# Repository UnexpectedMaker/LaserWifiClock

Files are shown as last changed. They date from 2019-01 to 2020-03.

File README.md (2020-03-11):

# Mod-able Laser Wifi Clock
Design files and code for my open source Mod-able RGB Laser Wifi Clock that I sell on tindie:
https://www.tindie.com/products/15501/

Laser Wifi Clock

It's custom hardware and custom code but all open source so if you want the challenge of making one yourself or you want to hack the code, go for it!

I have a live stream build of the board here if you want to see what's involved:
https://www.youtube.com/watch?v=2W7_SHC2Mis

# Design Files
Inlcluded in this reposity:
- EagleCAD schematics and Board layout files (Eagle 9.2) 
- Exported Gerber files (Gerber 274X)
- STL & DXF files for the 3D printed case and laser cut pieces
- Adrduino code

# Assembling the case
Here is a video guide to assembling the case

https://youtu.be/fARj-D6XGP0

# Hacking the code
You will need to have the ESP8266 board for Arduino IDE installed. If you don't, you can follow the instructions here:
https://arduino-esp8266.readthedocs.io/en/2.5.0-beta2/installing.html

Laser Wifi Clock

Once installed you'll need to select the *LOLIN(WEMOS) D1 R2 & Mini* as the board type.

Plus the following libraries from Library Manager
- One Button
- TimeLib
- WifiManager (tzapu)
- ArduinoJson

Enjoy!

# Support Unexpected Maker

I love designing, making and releasing our projects as open source. I do it because I believe it’s important to share knowledge and give back to the community, like many have done before me. It helps us all learn and grow.

That said, a lot of time, effort and finances have gone into designing and releasing these files, so please consider supporting me by buy some of my TiinyPICO products:

https://tinypico.com/shop

Or by buying one of our products on tindie:

https://www.tindie.com/stores/seonr/

Or by becoming a Patron:

https://www.patreon.com/unexpectedmaker

# Unexpected Maker
http://youtube.com/c/unexpectedmaker

http://twitter.com/unexpectedmaker

https://www.facebook.com/unexpectedmaker/

https://www.instagram.com/unexpectedmaker/

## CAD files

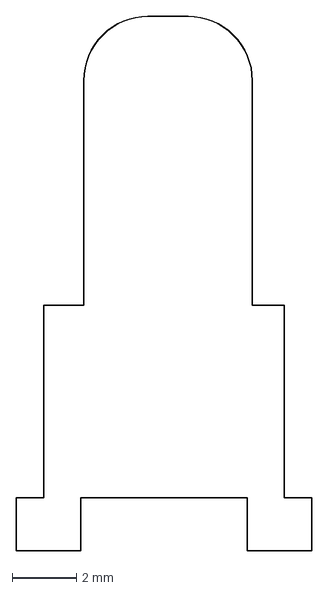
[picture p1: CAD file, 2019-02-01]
DXF/Clock_Segments_Short.dxf
9.20 x 16.7 mm

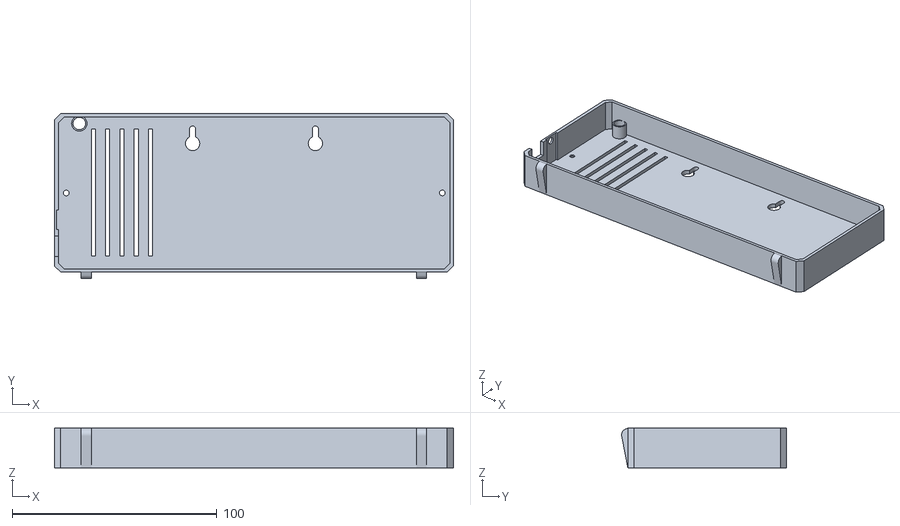
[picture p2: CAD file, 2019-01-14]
STL/WifiClock_Back.stl
195.0 x 80.6 x 19.5

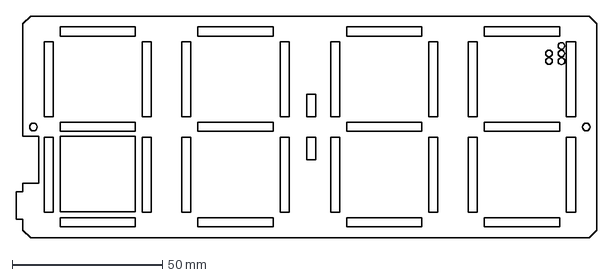
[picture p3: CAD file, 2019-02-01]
DXF/WifiClock_Acrylic_Middle.dxf
193.0 x 73.7 mm

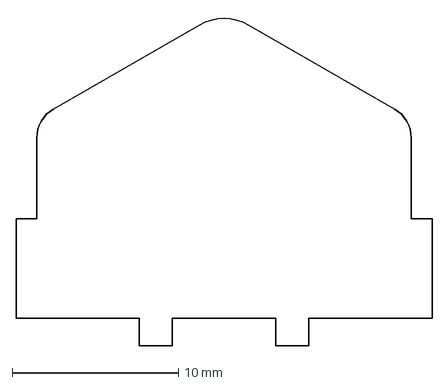
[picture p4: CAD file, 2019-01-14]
DXF/Clock_Segments_Long.dxf
25.0 x 19.8 mm

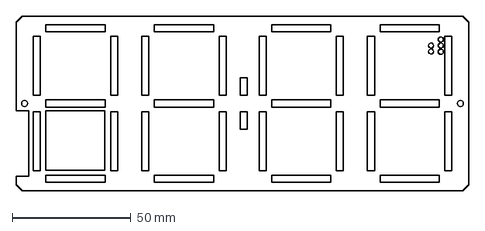
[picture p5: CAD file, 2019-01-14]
DXF/WifiClock_Acrylic_Back.dxf
190.8 x 73.7 mm

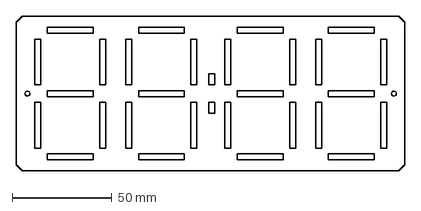
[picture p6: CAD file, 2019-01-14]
DXF/WifiClock_Acrylic_Front.dxf
195.0 x 77.6 mm

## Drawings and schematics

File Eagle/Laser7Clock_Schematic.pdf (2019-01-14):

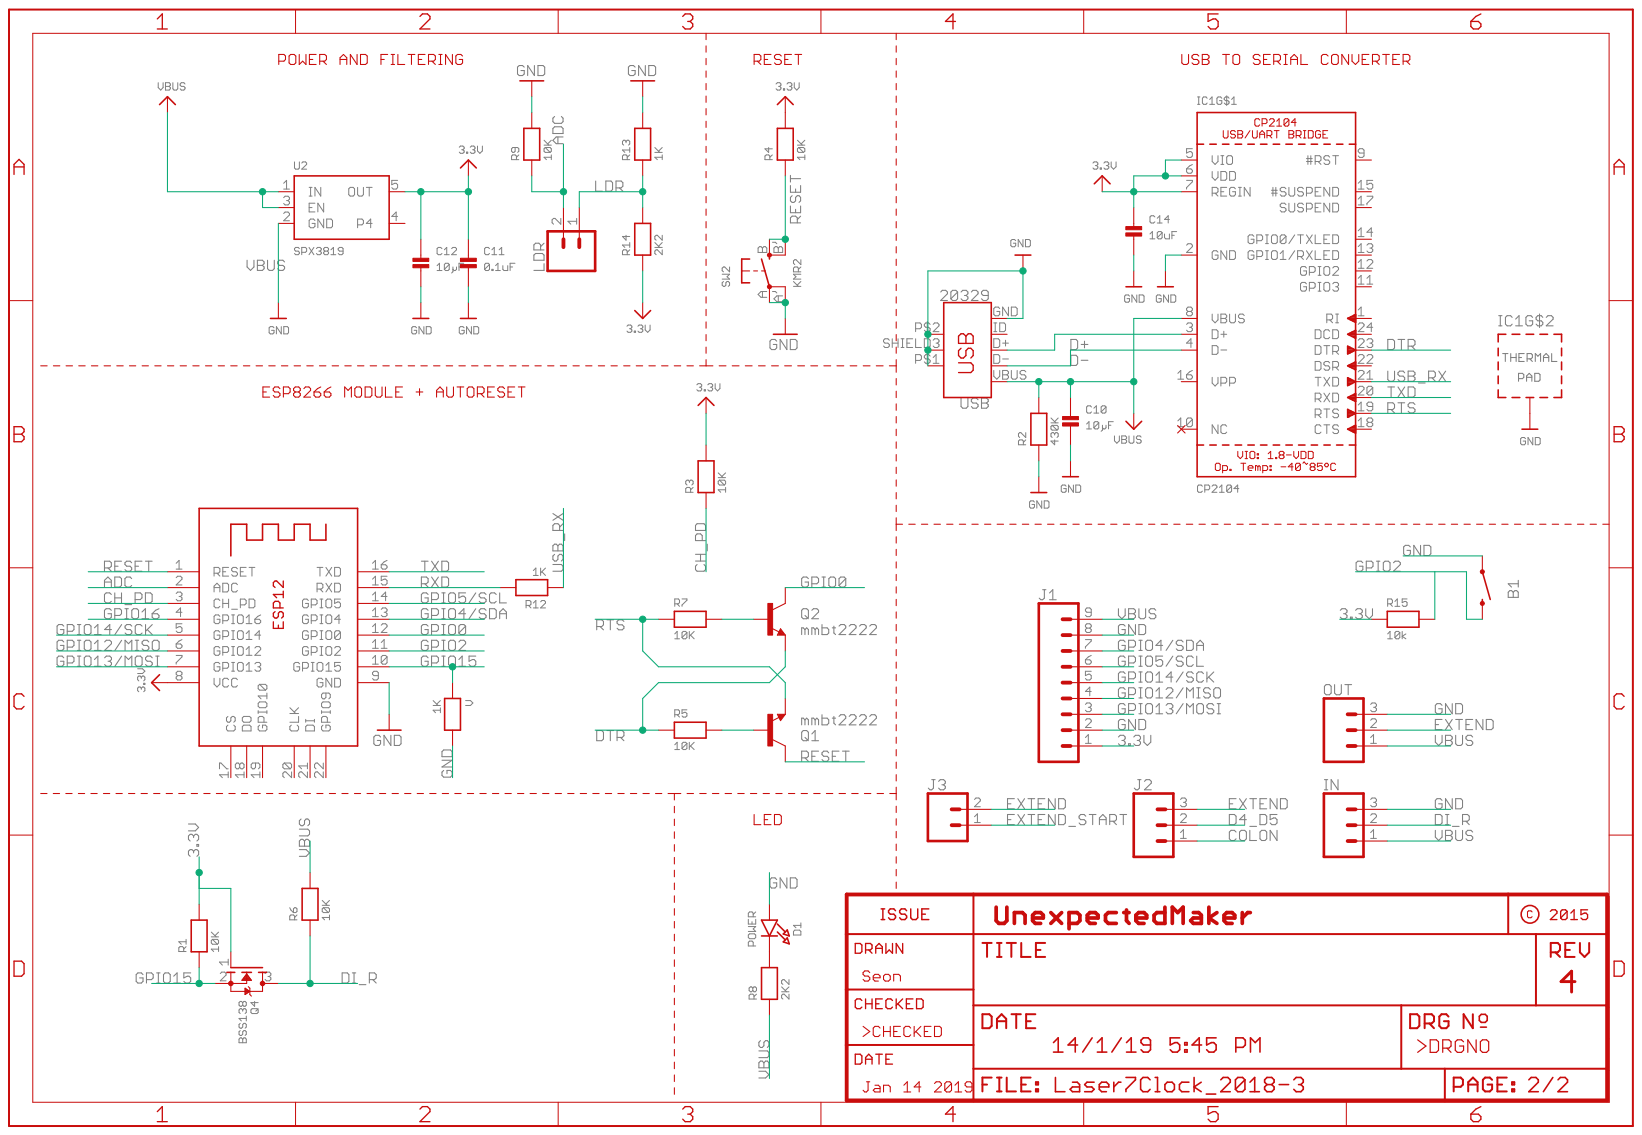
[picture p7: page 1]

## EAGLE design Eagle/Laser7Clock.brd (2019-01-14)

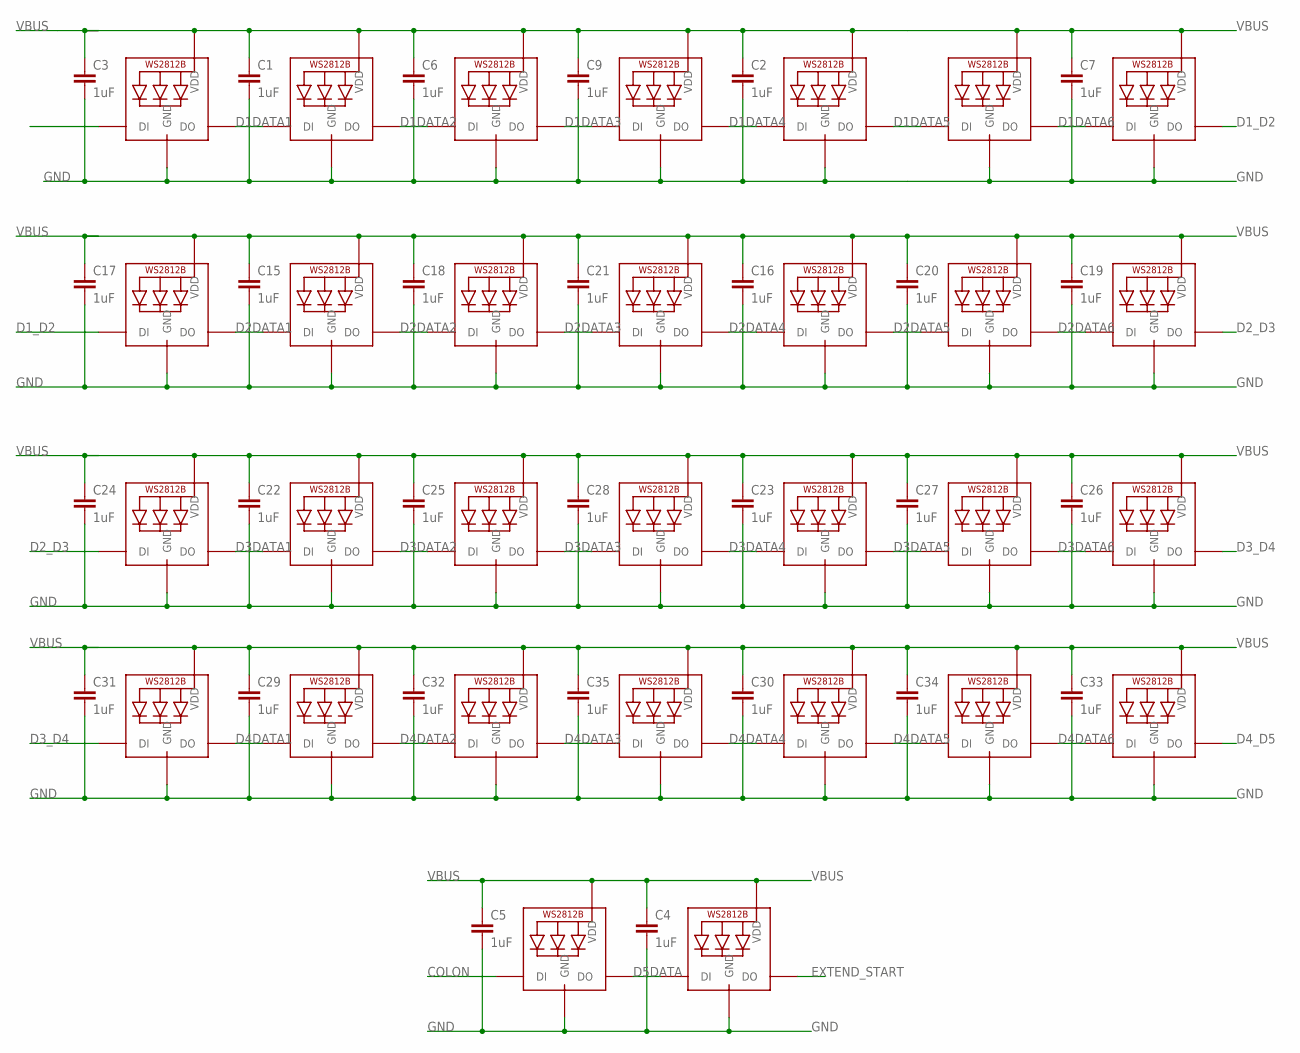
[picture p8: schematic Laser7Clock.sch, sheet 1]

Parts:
C1, C2, C3, C4, C5, C6, C7, C9, C15, C16, C17, C18, C19, C20, C21, C22, C23, C24, C25, C26, C27, C28, C29, C30, C31, C32, C33, C34, C35: 1uF; C0805K
D1L1, D1L2, D1L3, D1L4, D1L5, D1L6, D1L7, D2L1, D2L2, D2L3, D2L4, D2L5, D2L6, D2L7, D3L1, D3L2, D3L3, D3L4, D3L5, D3L6, D3L7, D4L1, D4L2, D4L3, D4L4, D4L5, D4L6, D4L7: WS2812B5050; WS2812B
LED1, LED2: WS2812B5050; WS2812B

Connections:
COLON: LED1.4-DIN (DI); also elsewhere on the board
D1DATA1: D1L1.2-DOUT (DO), D1L2.4-DIN (DI)
D1DATA2: D1L2.2-DOUT (DO), D1L3.4-DIN (DI)
D1DATA3: D1L3.2-DOUT (DO), D1L4.4-DIN (DI)
D1DATA4: D1L4.2-DOUT (DO), D1L5.4-DIN (DI)
D1DATA5: D1L5.2-DOUT (DO), D1L6.4-DIN (DI)
D1DATA6: D1L6.2-DOUT (DO), D1L7.4-DIN (DI)
D1_D2: D1L7.2-DOUT (DO), D2L1.4-DIN (DI)
D2DATA1: D2L1.2-DOUT (DO), D2L2.4-DIN (DI)
D2DATA2: D2L2.2-DOUT (DO), D2L3.4-DIN (DI)
D2DATA3: D2L3.2-DOUT (DO), D2L4.4-DIN (DI)
D2DATA4: D2L4.2-DOUT (DO), D2L5.4-DIN (DI)
D2DATA5: D2L5.2-DOUT (DO), D2L6.4-DIN (DI)
D2DATA6: D2L6.2-DOUT (DO), D2L7.4-DIN (DI)
D2_D3: D2L7.2-DOUT (DO), D3L1.4-DIN (DI)
D3DATA1: D3L1.2-DOUT (DO), D3L2.4-DIN (DI)
D3DATA2: D3L2.2-DOUT (DO), D3L3.4-DIN (DI)
D3DATA3: D3L3.2-DOUT (DO), D3L4.4-DIN (DI)
D3DATA4: D3L4.2-DOUT (DO), D3L5.4-DIN (DI)
D3DATA5: D3L5.2-DOUT (DO), D3L6.4-DIN (DI)
D3DATA6: D3L6.2-DOUT (DO), D3L7.4-DIN (DI)
D3_D4: D3L7.2-DOUT (DO), D4L1.4-DIN (DI)
D4DATA1: D4L1.2-DOUT (DO), D4L2.4-DIN (DI)
D4DATA2: D4L2.2-DOUT (DO), D4L3.4-DIN (DI)
D4DATA3: D4L3.2-DOUT (DO), D4L4.4-DIN (DI)
D4DATA4: D4L4.2-DOUT (DO), D4L5.4-DIN (DI)
D4DATA5: D4L5.2-DOUT (DO), D4L6.4-DIN (DI)
D4DATA6: D4L6.2-DOUT (DO), D4L7.4-DIN (DI)
D4_D5: D4L7.2-DOUT (DO); also elsewhere on the board
D5DATA: LED1.2-DOUT (DO), LED2.4-DIN (DI)
DI_R: D1L1.4-DIN (DI); also elsewhere on the board
EXTEND_START: LED2.2-DOUT (DO); also elsewhere on the board
GND: C1.2, C2.2, C3.2, C4.2, C5.2, C6.2, C7.2, C9.2, C15.2, C16.2, C17.2, C18.2, C19.2, C20.2, C21.2, C22.2, C23.2, C24.2, C25.2, C26.2, C27.2, C28.2, C29.2, C30.2, C31.2, C32.2, C33.2, C34.2, C35.2, D1L1.3-GND (GND), D1L2.3-GND (GND), D1L3.3-GND (GND), D1L4.3-GND (GND), D1L5.3-GND (GND), D1L6.3-GND (GND), D1L7.3-GND (GND), D2L1.3-GND (GND), D2L2.3-GND (GND), D2L3.3-GND (GND), D2L4.3-GND (GND), D2L5.3-GND (GND), D2L6.3-GND (GND), D2L7.3-GND (GND), D3L1.3-GND (GND), D3L2.3-GND (GND), D3L3.3-GND (GND), D3L4.3-GND (GND), D3L5.3-GND (GND), D3L6.3-GND (GND), D3L7.3-GND (GND), D4L1.3-GND (GND), D4L2.3-GND (GND), D4L3.3-GND (GND), D4L4.3-GND (GND), D4L5.3-GND (GND), D4L6.3-GND (GND), D4L7.3-GND (GND), LED1.3-GND (GND), LED2.3-GND (GND); also elsewhere on the board
VBUS: C1.1, C2.1, C3.1, C4.1, C5.1, C6.1, C7.1, C9.1, C15.1, C16.1, C17.1, C18.1, C19.1, C20.1, C21.1, C22.1, C23.1, C24.1, C25.1, C26.1, C27.1, C28.1, C29.1, C30.1, C31.1, C32.1, C33.1, C34.1, C35.1, D1L1.1-VDD (VDD), D1L2.1-VDD (VDD), D1L3.1-VDD (VDD), D1L4.1-VDD (VDD), D1L5.1-VDD (VDD), D1L6.1-VDD (VDD), D1L7.1-VDD (VDD), D2L1.1-VDD (VDD), D2L2.1-VDD (VDD), D2L3.1-VDD (VDD), D2L4.1-VDD (VDD), D2L5.1-VDD (VDD), D2L6.1-VDD (VDD), D2L7.1-VDD (VDD), D3L1.1-VDD (VDD), D3L2.1-VDD (VDD), D3L3.1-VDD (VDD), D3L4.1-VDD (VDD), D3L5.1-VDD (VDD), D3L6.1-VDD (VDD), D3L7.1-VDD (VDD), D4L1.1-VDD (VDD), D4L2.1-VDD (VDD), D4L3.1-VDD (VDD), D4L4.1-VDD (VDD), D4L5.1-VDD (VDD), D4L6.1-VDD (VDD), D4L7.1-VDD (VDD), LED1.1-VDD (VDD), LED2.1-VDD (VDD); also elsewhere on the board

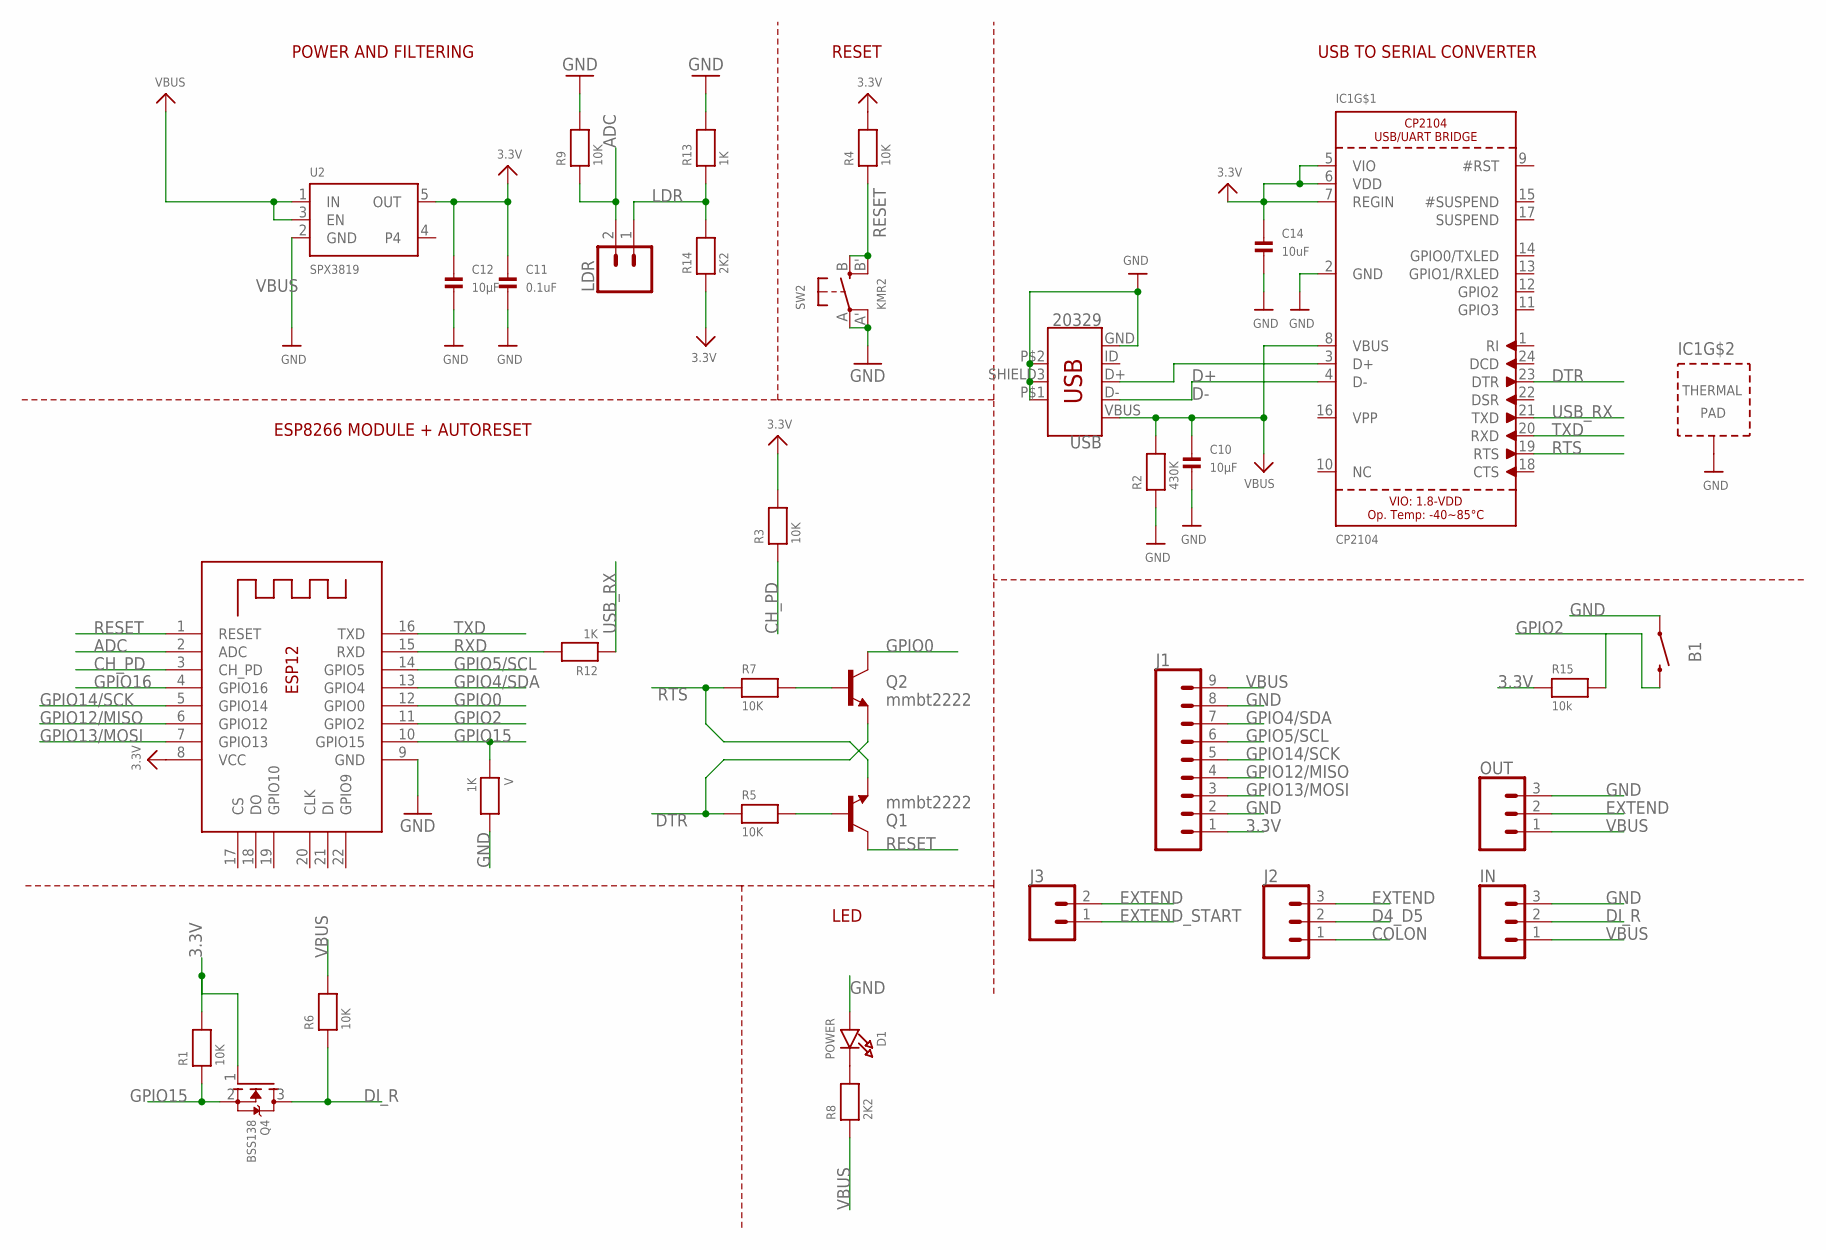
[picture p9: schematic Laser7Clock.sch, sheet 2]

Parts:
B1: MOMENTARY-SWITCH-SPST-PTH-RIGHT-ANGLE-KIT; TACTILE_SWITCH_PTH_RIGHT_ANGLE_KIT
C10, C12: 10µF; _0805MP
C11: 0.1uF; _0805MP
C14: 10uF; _0805MP
D1: POWER; CHIPLED_0805_NOOUTLINE
IC1: CP2104; QFN24_4MM_SMSC
IN: CONN_03LONGPADS; 1X03_LONGPADS
J1: CONN_09NO_SILK; 1X09_NO_SILK
J2: CONN_031X03_NO_SILK; 1X03_NO_SILK
J3: CONN_021X02_NO_SILK; 1X02_NO_SILK
LDR: CONN_021X02_NO_SILK; 1X02_NO_SILK
OUT: CONN_03LONGPADS; 1X03_LONGPADS
Q1, Q2: mmbt2222; SOT23-3
Q4: BSS138; SOT23-R
R1, R3, R4, R5, R6, R7: 10K; _0603MP
R2: 430K; _0805MP
R8, R14: 2K2; _0805MP
R9: 10K; _0805MP
R12: 1K; _0603MP
R13: 1K; _0805MP
R15: 10k; _0603MP
SW2: KMR2; BTN_KMR2_4.6X2.8
U2: SPX3819; SOT23-5
USB: 20329; USB-B-MICRO-SMD
V: 1K; _0603MP
X2: ESP-12; ESP-12E

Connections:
3.3V: C11.1, C12.1, C14.1, IC1.5 (VIO), IC1.6 (VDD), IC1.7 (REGIN), J1.1, Q4.1 (G), R1.2, R3.2, R4.2, R14.1, R15.1, U2.5 (OUT), X2.8 (VCC)
ADC: LDR.2, R9.1, X2.2 (ADC)
CH_PD: R3.1, X2.3 (CH_PD)
COLON: J2.1; also elsewhere on the board
D4_D5: J2.2; also elsewhere on the board
D+: IC1.3 (D+), USB.D+
D-: IC1.4 (D-), USB.D-
DI_R: IN.2, Q4.3 (D), R6.1; also elsewhere on the board
DTR: IC1.23 (DTR), Q2.2 (E), R5.1
EXTEND: J2.3, J3.2, OUT.2
EXTEND_START: J3.1; also elsewhere on the board
GND: B1.1, C10.2, C11.2, C12.2, C14.2, D1.A, IC1.2 (GND), IC1.THERM (TP), IN.3, J1.2, J1.8, OUT.3, R2.1, R9.2, R13.2, SW2.A, SW2.A' (P1), U2.2 (GND), USB.GND, USB.P$1 (SHIELD1), USB.P$2 (SHIELD2), USB.SHIELD3 (SHIELD), V.2, X2.9 (GND); also elsewhere on the board
GPIO0: Q2.3 (C), X2.12 (GPIO0)
GPIO2: B1.2, R15.2, X2.11 (GPIO2)
GPIO4/SDA: J1.7, X2.13 (GPIO4)
GPIO5/SCL: J1.6, X2.14 (GPIO5)
GPIO12/MISO: J1.4, X2.6 (GPIO12)
GPIO13/MOSI: J1.3, X2.7 (GPIO13)
GPIO14/SCK: J1.5, X2.5 (GPIO14)
GPIO15: Q4.2 (S), R1.1, V.1, X2.10 (GPIO15)
GPIO16: X2.4 (GPIO16)
LDR: LDR.1, R13.1, R14.2
unnamed: D1.C, R8.2
unnamed: Q1.1 (B), R5.2
unnamed: Q2.1 (B), R7.2
RESET: Q1.3 (C), R4.1, SW2.B (S), SW2.B' (S1), X2.1 (RESET)
RTS: IC1.19 (RTS), Q1.2 (E), R7.1
RXD: R12.2, X2.15 (RXD)
TXD: IC1.20 (RXD), X2.16 (TXD)
USB_RX: IC1.21 (TXD), R12.1
VBUS: C10.1, IC1.8 (VBUS), IN.1, J1.9, OUT.1, R2.2, R6.2, R8.1, U2.1 (IN), U2.3 (EN), USB.VBUS; also elsewhere on the board

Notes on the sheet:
POWER AND FILTERING
RESET
USB TO SERIAL CONVERTER
LED
ESP8266 MODULE + AUTORESET

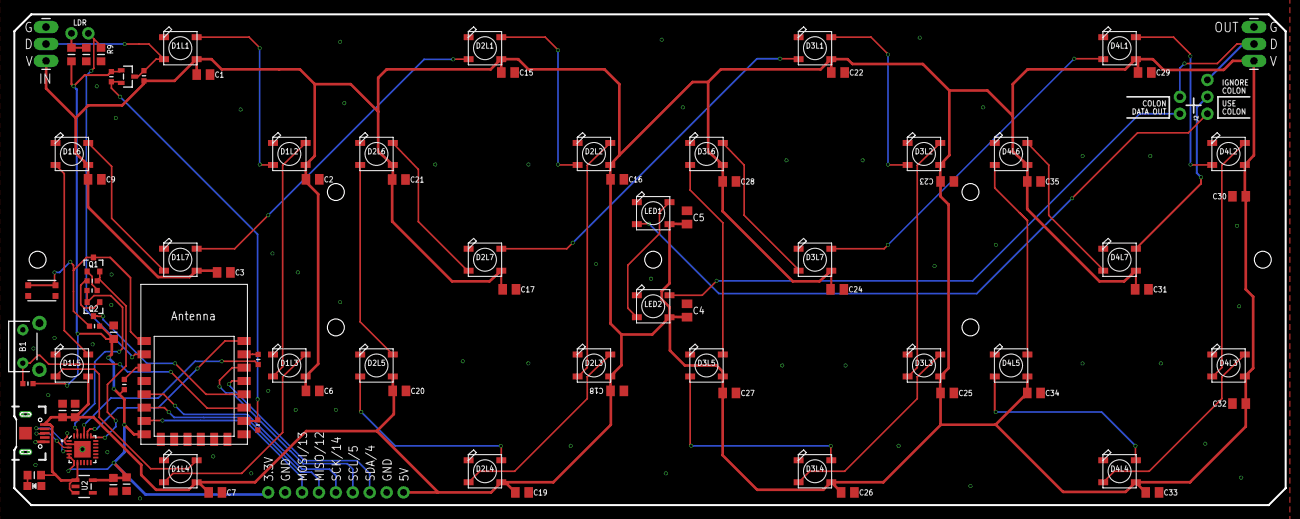
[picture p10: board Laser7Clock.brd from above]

Board: 2 copper layers, 190.8 x 73.7 mm, 93 parts (0 on the bottom side), 58 nets.

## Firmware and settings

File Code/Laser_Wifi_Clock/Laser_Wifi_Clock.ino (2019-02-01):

#include "Laser7WifiClock.h"
#include "OneButton.h" // Library Manager

#include <ArduinoJson.h>

#include <TimeLib.h>

#include "FS.h"
#include "math.h";

#include <ESP8266WiFi.h>
#include <ESP8266WebServer.h>
#include <ESP8266mDNS.h>
#include <WiFiManager.h>         //https://github.com/tzapu/WiFiManager

/**** NTP Client Stuff ***/
#include <WiFiUdp.h>
unsigned int localPort = 2390;      // local port to listen for UDP packets
IPAddress timeServerIP; // time.nist.gov NTP server address
String ntpServerName = "time.nist.gov";
const int NTP_PACKET_SIZE = 48; // NTP time stamp is in the first 48 bytes of the message
byte packetBuffer[ NTP_PACKET_SIZE]; //buffer to hold incoming and outgoing packets

WiFiUDP udp;

uint8_t ntpSuccess = 0;
uint8_t ntpFailed = 0;
uint8_t ntpLoop = 0;
uint8_t ipResets = 0;

bool didSecondSwitch = false;
bool didMinuteSwitch = false;
int lastHour = 0;
int currentUpdateCheck = 0;

bool gotTimeFromServer = false;

const int SAVE_VERSION = 1;

time_t prevDisplay = 0;

bool flashConnect = false;
bool flashConnectState = false;

float valLDR = 0;

bool isReady = false;
bool isReboot = false;

unsigned long previousMillis = 0;
unsigned long previousTimeCheck = 0;

int visualState = 0;
int rainbow = 0;
int showingIP = 0;

String settings_filename = "settings.json";

Laser7WifiClock disp( 4, 15, 2 );

#define BUTTON 2
OneButton button (BUTTON, true);

ESP8266WebServer server(80);
WiFiManager wifiManager;

struct Settings {
  int ver = 0;
  int visualstate = 0;
  int timeformat = 24;
  bool useLDR = true;
  float gmt = -1000;
  int brightness = 80;
  int updateSchedule = 1;
  uint32_t defcolour_d = 0;
  uint32_t defcolour_c = 0;
  int daylightstart_d = 0;
  int daylightstart_m = 0;
  int daylightstart_t = 0;
  int daylightend_d = 0;
  int daylightend_m = 0;
  int daylightend_t = 0;
  String ntpserver;
};

Settings settings;

void setup()
{
  flashConnect = false;
  
  pinMode( BUTTON, INPUT );
  button.attachClick(ButtonClick);
  button.attachDoubleClick(ButtonDoubleClick);
  button.attachLongPressStop(ButtonLongPress);

  previousMillis = millis();
  isReady = false;
  Serial.begin(115200);
  disp.Begin( 50 ); // set brightness to 33%
  delay(100);

  valLDR = analogRead(A0);

  disp.DisplayTextColor( "-   ", disp.Color(0,255,0) );

  LoadSettings();

  delay(500);

  WiFi.hostname("LaserWifiClock");

  bootWifi();
}

void configModeCallback (WiFiManager *myWiFiManager)
{
  Serial.println("Entered config mode");

  ClearAll();
  disp.DisplayTextColor( "conf", disp.Color(0,155,0) );

  Serial.println(WiFi.softAPIP());
  //if you used auto generated SSID, print it
  Serial.println(myWiFiManager->getConfigPortalSSID());
  Serial.println("Need new Wifi credentials!");
}


void bootWifi()
{
  disp.DisplayTextColor( "--  ", disp.Color(0,0,255) );
    
  Serial.println("Connecting via WifiManager...");
  WiFi.setSleepMode(WIFI_NONE_SLEEP);

  isReboot = false;

  wifiManager.setTimeout(180);
  wifiManager.setAPCallback(configModeCallback);

  if(!wifiManager.autoConnect("LaserWiFiClock"))
  {
    Serial.println("failed to connect and hit timeout");

    ClearAll();
    disp.DisplayTextColor( "err", disp.Color(255,0,0) );

    isReady = false;
    
    isReboot = true;

    delay(2000);
    ClearAll();
    disp.DisplayTextColor( "3", disp.Color(155,0,0) );
    delay(1000);
    disp.DisplayTextColor( "2", disp.Color(155,0,0) );
    delay(1000);
    disp.DisplayTextColor( "1", disp.Color(155,0,0) );
    delay(1000);
    ClearAll();

    ESP.restart();
  }
  else
  {
    disp.DisplayTextColor( "--- ", disp.Color(0,255,255) );
    
    delay(1000);
    bool haveTime = false;

    while (!gotTimeFromServer )
    {
      gotTimeFromServer = GetTimeFromServer();
      if ( !gotTimeFromServer )
      {
        disp.DisplayTextColor( "----", disp.Color(255,0,255) );
        delay(1000);
        disp.DisplayTextColor( "--- ", disp.Color(0,255,255) );
        delay(1000);
      }
    }

    StartWebServer();
    
    disp.DisplayTextColor( "----", disp.Color(0,255,0) );

    Serial.print("Wifi Strength: ");
    Serial.print( getWifiQuality() );
    Serial.println("%");

    delay(500);
    isReady = true;
  }
}


void bootWifiQuiet()
{
  Serial.println("Stopping webserver...");
  server.stop();

  Serial.println("QUIET: Connecting via WifiManager...");
  
  WiFiManager wifiManager;
  wifiManager.setTimeout(180);
  wifiManager.setAPCallback(configModeCallback);
  
  if(!wifiManager.autoConnect("LaserWIFIClock"))
  {
    Serial.println("failed to connect and hit timeout");
    isReady = false;
    ClearAll();
    //disp.DisplayTextColor( "err", disp.Color(255,0,0) );
    flashConnect = true;
    delay(500);
  }
  else
  {
    delay(100);
    Serial.println("Starting UDP");
    udp.begin(localPort);
    Serial.print("Local port: ");
    Serial.println(udp.localPort());

    gotTimeFromServer = false;

    while (!gotTimeFromServer )
    {
      gotTimeFromServer = GetTimeFromServer();
      if ( !gotTimeFromServer )
      {
        delay(2000);
      }
    }

    StartWebServer();

    ipResets++;

    Serial.print("Wifi Strength: ");
    Serial.print( getWifiQuality() );
    Serial.println("%");
    
    isReady = true;
  }
}

void ResetSettings()
{
  settings.ver = SAVE_VERSION;
  settings.ntpserver = String( ntpServerName );
  settings.visualstate = 0;
  settings.timeformat = 24;
  settings.useLDR = true;
  settings.gmt = -1000;
  settings.updateSchedule = 1;
  settings.brightness = 80;
  settings.defcolour_d = Color(0,0,255);
  settings.defcolour_c = Color(255,0,0);
  settings.daylightstart_d = 0;
  settings.daylightstart_m = 0;
  settings.daylightstart_t = 0;
  settings.daylightend_d = 0;
  settings.daylightend_m = 0;
  settings.daylightend_t = 0;
}

void LoadSettings()
{
  // always use this to "mount" the filesystem
  bool result = SPIFFS.begin();

  if ( result )
  {
    delay(100);
  
    DynamicJsonBuffer settingsBuffer;
  
    // this opens the file "f.txt" in read-mode
    File f = SPIFFS.open(settings_filename , "r");
    
    if (!f || f.size() < 1 ) 
    {
      Serial.println("LOAD: File doesn't exist yet. Creating it");
  
      // open the file in write mode
      File f = SPIFFS.open(settings_filename, "w");
      if (!f)
      {
        Serial.println("LOAD: File creation failed");
        return;
      }

      flashConnect = true;
      SaveSettings();
    }
    else
    {
      delay(100);
  
//      Serial.print("Size? ");
//      Serial.println( f.size() );
//  
//      Serial.print("Left? ");
//      Serial.println( f.available() );
      
      if ( f.available() == 0 )
      {
          Serial.println("LOAD: Counldn't grab data, so stomping..");
          ResetSettings();
          SaveSettings();

          flashConnect = true;
       }
       else
       {
        // we could open the file
        while(f.available() )
        {
          //Lets read line by line from the file
          String line = f.readStringUntil('\n');
    
          // check we have data and then copy over?
          if ( line.startsWith("{\"ver") )
          {
            Serial.println( "LOAD: Found JSON Settings" );
            Serial.println( "LOAD: " + line );
            
            // extract JSON
            JsonObject& jdata = settingsBuffer.parseObject(line);
            
            settings.ver = jdata["ver"];
    
            if ( settings.ver == SAVE_VERSION )
            {
              settings.timeformat = jdata["timeformat"]; 
              settings.visualstate = jdata["visualstate"];
              settings.brightness = jdata["brightness"]; 
              settings.gmt = jdata["gmt"]; 
              settings.useLDR = jdata["useLDR"];
              settings.updateSchedule = jdata["updateSchedule"];
              settings.defcolour_d = jdata["defcolour_d"]; 
              settings.defcolour_c = jdata["defcolour_c"]; 
              settings.daylightstart_d = jdata["daylightstart_d"];
              settings.daylightstart_m = jdata["daylightstart_m"]; 
              settings.daylightstart_t = jdata["daylightstart_t"]; 
              settings.daylightend_d = jdata["daylightend_d"];
              settings.daylightend_m = jdata["daylightend_m"];
              settings.daylightend_t = jdata["daylightend_t"];
              settings.ntpserver = jdata["ntpserver"].as<String>();
            }
            else
            {
              Serial.print("LOAD: Old save version found : ");
              Serial.print( settings.ver );
              Serial.print(", Current: ");
              Serial.println( SAVE_VERSION );
              Serial.println( "LOAD: Stompoing data, sorry!" );
              
              ResetSettings();
              SaveSettings();
            }
          }
          else
          {
            Serial.println("LOAD: No save version found, stomping");
            ResetSettings();
            SaveSettings();
          }
        }
      }
       
      if ( settings.gmt > -1000 )
        flashConnect = false;
    }
  f.close();
  }
  else
  {
    Serial.println("SAVE: Failed mounting SPIFFS");
  }
}


bool IsDaylightSaving()
{
  // if start day is 0 ignore daylight savings settings
  if ( settings.daylightstart_d == 0 || settings.daylightstart_m == 0 )
      return false;
      
  // if start and end months are the same, never set daylight saving to true
  if ( settings.daylightstart_m == settings.daylightend_m )
      return false;

  // if start is later than end  oct -> april
  if ( settings.daylightstart_m > settings.daylightend_m )
  {
    if ( month() < settings.daylightstart_m && month() > settings.daylightend_m )
      return false;
  }
  else
  {
    if ( month() < settings.daylightstart_m || month() > settings.daylightend_m )
      return false;
  }

  if ( month() == settings.daylightstart_m && day() < settings.daylightstart_d )
    return false;

  if ( month() == settings.daylightstart_m && day() == settings.daylightstart_d && hour() < settings.daylightstart_t )
    return false;

  if ( month() == settings.daylightend_m && day() > settings.daylightend_d )
    return false;

  if ( month() == settings.daylightend_m && day() == settings.daylightend_d && hour() > settings.daylightend_t )
    return false;
  
    return true;
 
}

bool Is24Hour() 
{
  return ( settings.timeformat == 24 );
}

void SaveSettings()
{
  // always use this to "mount" the filesystem
  bool result = SPIFFS.begin();

  if ( result )
  {
    // this opens the file "f.txt" in write mode
    File f = SPIFFS.open(settings_filename , "w");
    
    if (!f) 
    {
      Serial.println("SAVE: File creation failed");
      return;
    }
  
    DynamicJsonBuffer settingsBuffer;
    JsonObject &jdata = settingsBuffer.createObject();
  
     jdata["ver"] = SAVE_VERSION;
     jdata["timeformat"] = settings.timeformat; 
     jdata["visualstate"] = settings.visualstate;
     jdata["brightness"] = settings.brightness; 
     jdata["useLDR"] = settings.useLDR;
     jdata["gmt"] = settings.gmt; 
     jdata["updateSchedule"] = settings.updateSchedule;
     jdata["defcolour_d"] = settings.defcolour_d;
     jdata["defcolour_c"] = settings.defcolour_c; 
     jdata["daylightstart_d"] = settings.daylightstart_d; 
     jdata["daylightstart_m"] = settings.daylightstart_m; 
     jdata["daylightstart_t"] = settings.daylightstart_t; 
     jdata["daylightend_d"] = settings.daylightend_d; 
     jdata["daylightend_m"] = settings.daylightend_m;
     jdata["daylightend_t"] = settings.daylightend_t;
     jdata["ntpserver"] = settings.ntpserver;
  
    String output;
    jdata.printTo(output);
  
    Serial.print ("JSON: ");
    Serial.println( output );
  
    f.println( output );
        
    Serial.println( "Settings saved");
  
    f.close();
  }
  else
  {
    Serial.println("SAVE: Failed mounting SPIFFS");
  }
}


void StartWebServer()
{
  if (MDNS.begin("LaserWiFiClock"))
  {
    Serial.println("MDNS responder started");
  }

  server.on("/", handleRoot);
  server.on("/f12", handleF12);
  server.on("/f24", handleF24);

  server.on("/inline", []() {
    server.send(200, "text/plain", "this works as well");
  });

  server.onNotFound(handleNotFound);

  server.begin();
  Serial.println("HTTP server started");
}

void handleF12()
{
  settings.timeformat = 12;
  Serial.println("Time is now 12 hour");
  // Redirect to /
  server.sendHeader("Location", String("/"), true);
  server.send ( 302, "text/plain", "");
  // Save settings
  SaveSettings();
}

void handleF24()
{
  settings.timeformat = 24;
  Serial.println("Time is now 24 hour");
  // Redirect to /
  server.sendHeader("Location", String("/"), true);
  server.send ( 302, "text/plain", "");
  // Save settings
  SaveSettings();
}

String GetNTPServer()
{
  if ( settings.ntpserver.length() < 1 || settings.ntpserver == NULL )
    return  ntpServerName;
  else
    return settings.ntpserver;
  
}
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
void loop()
{
  // Check for button press
  button.tick();

  if ( settings.useLDR )
  {
    // Adjust brightness based on LDR readings
    valLDR = analogRead(A0);
    float bright = constrain(( ( valLDR / 555 )) * settings.brightness, 15, 80);
    disp.SetBrightness( bright );
  }
  else
  {
     float bright = map( settings.brightness, 33,100, 15, 80);
      disp.SetBrightness( bright );
  }

  if ( flashConnect || settings.gmt < -999 )
  {
    if ( ShowIP() )
    {
      // nothing here... showing of IP is in the ShowIP() method
    }
    else
    {
      if (  millis() - previousMillis > 500 )
      {
        if ( flashConnectState )
          disp.DisplayError( disp.Color(255,0,0) );
        else
          ClearAll();
  
        flashConnectState = !flashConnectState;
        previousMillis = millis();
      }
    }

    if ( settings.gmt < -999 )
    {
      // run the webserver
      server.handleClient();
      return;
    }
  }
    
  // If wifi is not connected with correct time from NPT, don't go any further
  if ( !isReady )
    return;

  if ( flashConnect )
    flashConnect  = false;

  // run the webserver
  server.handleClient();

  bool hourSwitched = false;
  didSecondSwitch = false;
  if (now() != prevDisplay)
  {
    prevDisplay = now();

    // Log the time and date to the serial console
    //digitalClockDisplay();
    
    didSecondSwitch = true;

    if ( lastHour != hour() )
    {
      lastHour = hour();
      hourSwitched = true;
    }

    // make sure we only do this once in the loop per second == 0
    if ( didSecondSwitch )
    {
      // every 60 seconds we check for IP
      if (second() < 1 )
      {
        Serial.print(">>>>>>>>>>>>>> Free Heap: ");
        Serial.println( ESP.getFreeHeap() );
        
        Serial.println(">>>>>>>>>>>>>> Check WiFi"); 
        if ( WiFi.status() != WL_CONNECTED )
        {
          Serial.print("**** WiFi Disconnected: ");
          Serial.println ( String((wl_status_t)WiFi.status()) ); 
          bootWifiQuiet();
          return;
        }
      }
    }

    // every hour we grab the correct time from NTP and adjust the clock
    if ( hourSwitched )
    {
      hourSwitched = false;
  
      if ( currentUpdateCheck >= settings.updateSchedule )
      {
        gotTimeFromServer = GetTimeFromServer();
      }
      else
      {
        currentUpdateCheck++;
      }
    }
  }

  // Show IP to the user if they selected it with a dbl press of the button
  if ( ShowIP() )
  {
    // nothing here... showing of IP is in the ShowIP() method  
  }
  else // show the time based on the visual display settings chosen
  {
    if ( settings.visualstate == 0 )
    {
      if ( didSecondSwitch )
        disp.DisplayTime( GetHour(), GetMins(), second(), settings.defcolour_d, settings.defcolour_c );
    }
    else if ( settings.visualstate == 1 )
    {
      uint32_t col = disp.Wheel(rainbow & 255);
      disp.DisplayTime( GetHour(), GetMins(), second(), col );
  
      if (  millis() - previousMillis > 33 )
      {
        previousMillis = millis();
        rainbow++;
      }
    }
    else if ( settings.visualstate == 2 )
    {
      if ( millis() %2 == 0 )
        disp.DisplayTimeCycleH( GetHour(), GetMins(), second(), rainbow, -1 );
  
      if (  millis() - previousMillis > 33 )
      {
        previousMillis = millis();
        rainbow++;
      }
    }
    else if ( settings.visualstate == 3 )
    {
      disp.DisplayTimeCycleV( GetHour(), GetMins(), second(), rainbow, 1 );
  
      if (  millis() - previousMillis > 33 )
      {
        previousMillis = millis();
        rainbow++;
      }
    }
    else if ( settings.visualstate == 4 )
    {
      if ( didSecondSwitch )
        disp.DisplayTimeRandom( GetHour(), GetMins(), second() );
    }
    else if ( settings.visualstate == 5 )
    {
      disp.DisplayTimeVerticalRainbow( GetHour(), GetMins(), second(), disp.Color( 255, 255, 0), disp.Color(0, 200, 0) );
    }
  }
}


// methods for managing Hour and Mins
int GetHour()
{
  int newHour = hour() + ( IsDaylightSaving() ? 1 : 0 );

  if ( !Is24Hour() )
  {
    if ( newHour > 12 )
      newHour -= 12;
  }
  else if ( newHour > 23 )
  {
    newHour -= 24;
  }

  return newHour;
}


int GetMins()
{
  int newMins = minute();
  return newMins;
}

// Clear all pixels on the display
void ClearAll()
{
    disp.ClearAll();
}

// Handle all of the button clicks
void ButtonClick()
{
  if ( showingIP == 0 )
  {
    settings.visualstate++;
    if ( settings.visualstate == 6)
      settings.visualstate = 0;

    SaveSettings();
    
    previousMillis = millis();
  }
}

void ButtonDoubleClick()
{
  if ( showingIP == 0 )
  {
    showingIP = 5;
    previousMillis = millis() -2000;
  }
}

void ButtonLongPress()
{
  WiFiManager wifiManager;
  wifiManager.resetSettings();
  delay(1000);

  Serial.println( "Re connect");
  bootWifi();
}


// NTP and Wifi Utils
// get time from server
bool GetTimeFromServer()
{
  Serial.println("Starting UDP");
  udp.begin(localPort);
  Serial.print("Local port: ");
  Serial.println(udp.localPort());

  if ( ntpLoop < 5 )
  {
    //get a random server from the pool
    WiFi.hostByName( string2constchar(GetNTPServer()), timeServerIP);
  }
  else
  {
    settings.ntpserver = ntpServerName;
    WiFi.hostByName( string2constchar(GetNTPServer()), timeServerIP);
  }

  sendNTPpacket(timeServerIP); // send an NTP packet to a time server
  // wait to see if a reply is available
  delay(1000);
  
  int cb = udp.parsePacket();
  if (!cb) {
    Serial.println("no packet yet");

    ntpFailed++;
    ntpLoop++;

    udp.stop();
    
    return false;
  }
  else {
    Serial.print("packet received, length=");
    Serial.println(cb);
    // We've received a packet, read the data from it
    udp.read(packetBuffer, NTP_PACKET_SIZE); // read the packet into the buffer

    //the timestamp starts at byte 40 of the received packet and is four bytes,
    // or two words, long. First, esxtract the two words:

    unsigned long highWord = word(packetBuffer[40], packetBuffer[41]);
    unsigned long lowWord = word(packetBuffer[42], packetBuffer[43]);
    // combine the four bytes (two words) into a long integer
    // this is NTP time (seconds since Jan 1 1900):
    unsigned long secsSince1900 = highWord << 16 | lowWord;
    Serial.print("Seconds since Jan 1 1900 = " );
    Serial.println(secsSince1900);

    // now convert NTP time into everyday time:
    Serial.print("Unix time = ");
    // Unix time starts on Jan 1 1970. In seconds, that's 2208988800:
    const unsigned long seventyYears = 2208988800UL;
    // subtract seventy years:
    unsigned long epoch = secsSince1900 - seventyYears;
    // print Unix time:
    Serial.println(epoch);

    //time_t theTime = epoch + settings.gmt * SECS_PER_HOUR;
    setTime( epoch + settings.gmt * SECS_PER_HOUR );

    ntpSuccess++;
    ntpLoop = 0;  
    udp.stop();

    currentUpdateCheck = 0;

    lastHour = hour();

    previousTimeCheck = millis();
    
    return true;
  }
}


// send an NTP request to the time server at the given address
unsigned long sendNTPpacket(IPAddress& address)
{
  Serial.println("sending NTP packet...");
  // set all bytes in the buffer to 0
  memset(packetBuffer, 0, NTP_PACKET_SIZE);
  // Initialize values needed to form NTP request
  // (see URL above for details on the packets)
  packetBuffer[0] = 0b11100011;   // LI, Version, Mode
  packetBuffer[1] = 0;     // Stratum, or type of clock
  packetBuffer[2] = 6;     // Polling Interval
  packetBuffer[3] = 0xEC;  // Peer Clock Precision
  // 8 bytes of zero for Root Delay & Root Dispersion
  packetBuffer[12]  = 49;
  packetBuffer[13]  = 0x4E;
  packetBuffer[14]  = 49;
  packetBuffer[15]  = 52;

  // all NTP fields have been given values, now
  // you can send a packet requesting a timestamp:
  udp.beginPacket(address, 123); //NTP requests are to port 123
  udp.write(packetBuffer, NTP_PACKET_SIZE);
  udp.endPacket();
}

// converts the dBm to a range between 0 and 100%
int8_t getWifiQuality()
{
  int32_t dbm = WiFi.RSSI();
  if(dbm <= -100) {
      return 0;
  } else if(dbm >= -50) {
      return 100;
  } else {
      return 2 * (dbm + 100);
  }
}

uint32_t Color(uint8_t r, uint8_t g, uint8_t b)
{
  return ((uint32_t)r << 16) | ((uint32_t)g <<  8) | b;
}

#include "webcode.h";


void handleRoot()
{
  server.send(200, "text/html", getPage() );
}

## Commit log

2019-01-14 Initial commit... more to come!
    [Clock_Segments_Long_09b.dxf, Laser7Clock.brd, Laser7Clock.sch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]
2019-02-01 Addition of Arduino code
2019-02-01 Added Arduino code
2019-02-01 Updated acrylic DFX files
    [WifiClock_Acrylic_Back.dxf, WifiClock_Acrylic_Front.dxf, WifiClock_Acrylic_Middle.dxf]
2019-02-01 Added missing colon segment design & renamed digit segment file
    [Clock_Segments_Long.dxf, Clock_Segments_Short.dxf]

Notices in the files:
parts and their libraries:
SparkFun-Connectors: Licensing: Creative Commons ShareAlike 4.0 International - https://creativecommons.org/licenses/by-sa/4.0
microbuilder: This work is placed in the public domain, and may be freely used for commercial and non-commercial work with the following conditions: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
